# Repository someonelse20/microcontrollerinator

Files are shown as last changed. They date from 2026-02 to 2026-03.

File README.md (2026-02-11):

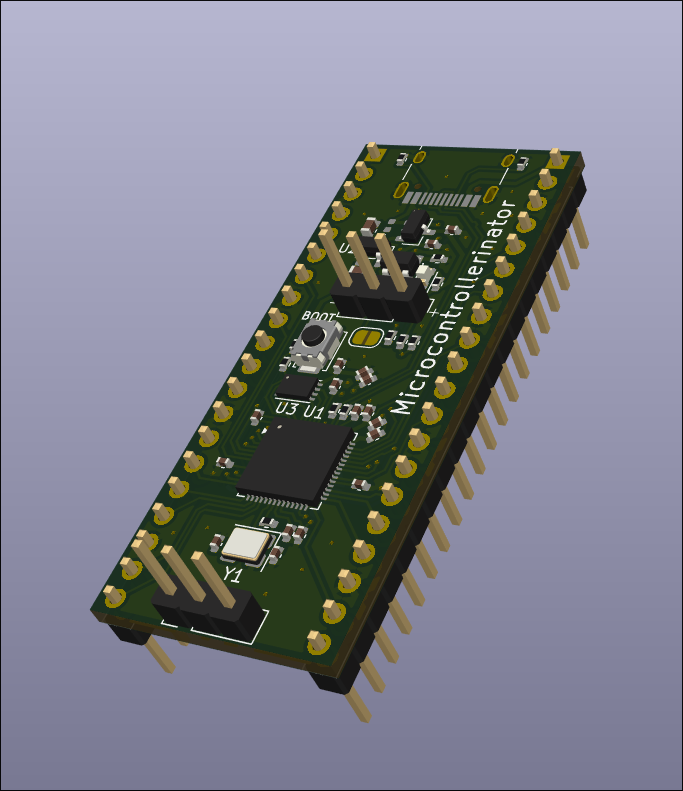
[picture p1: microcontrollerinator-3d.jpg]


# Microcontrollerinator
Simple custom devboard based on the RP2040 with an integraded 1 cell li-ion charger and Dr. Doofenshmirtz because why not.
This is my first complex pcb and to get my feet wet I mostly followed the example at https://blueprint.hackclub.com/starter-projects/devboard and added the BQ21040DBV battery charger. 

# How To Use
The board has the same pinout as the Raspberry Pi Pico exept ADC_VREF is GPIO23, 3V3_EN is GPIO24, and VSYS is GPIO25. GPIO29_ADC3 monitors the voltage of the battery multiplied by 1.3125 due to the resistor dividor. Pressing the switch will put the RP2040 into boot mode so it can be programed. The VBUS pin will output the current power supply voltage which will be 5v when plugged in but will be the direct battery voltage when unplugged. The battery pin headder has three pins, two for power and one for a thermistor to monitor temperature. The thermistor can be left hanging but there is a solder pad that enables a pull up resistor which is recomended in the charger datasheet.

# Schematic
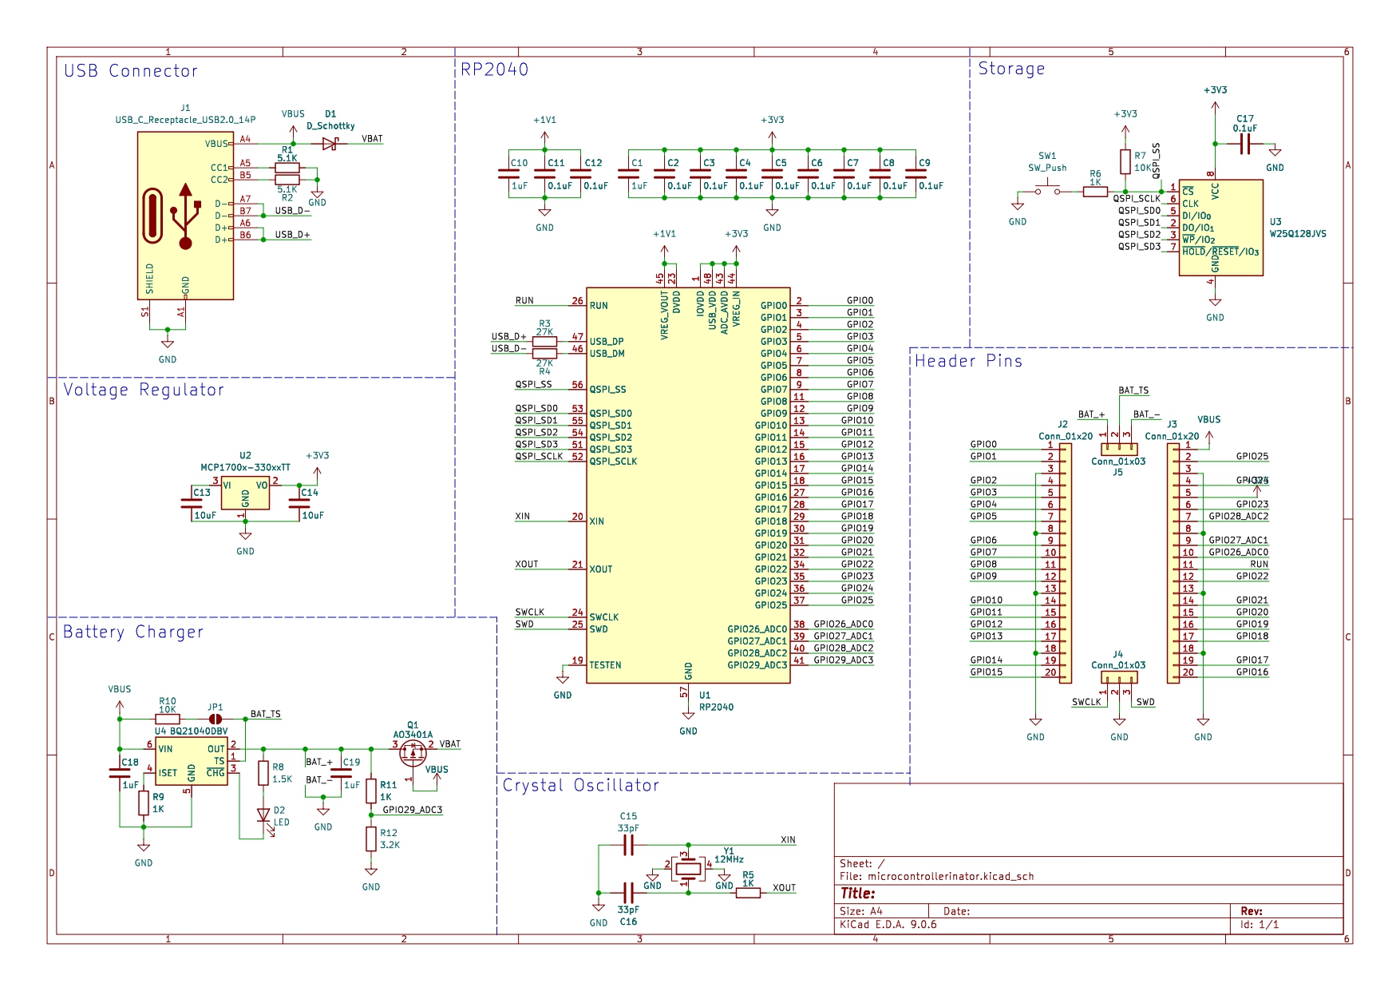
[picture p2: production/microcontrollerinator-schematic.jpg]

# PCB
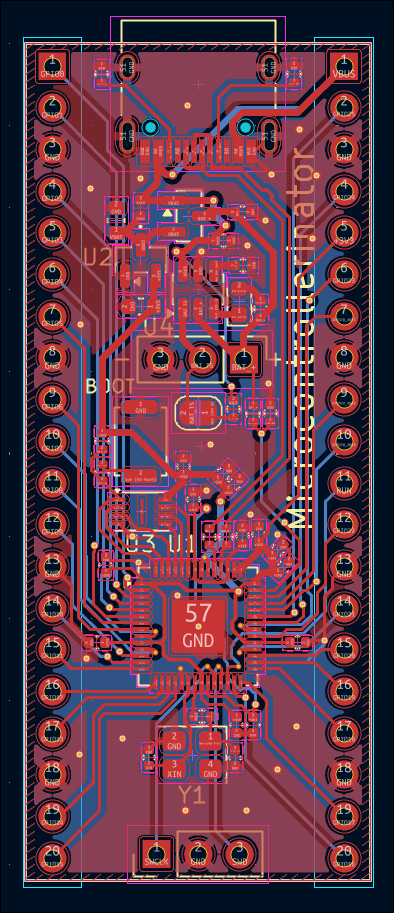
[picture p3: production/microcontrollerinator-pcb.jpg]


# Ordering
This bom file, the cpl position file, and the gerber zip files are in the production folder and formated to be orederd from https://jlcpcb.com/. The positions file needs to be edited a bit and there isn't an option to export the updated cpl file for JLCPCB so edit as show in the picture below. The USB header goes down a little, U2 pin 1 goes to the bottom left, U3 pin 1 goes to the top left, U4 pin 1 goes to the bottom left, and Q1 pin 1 goes to the top left.
| Id | Designator | Footprint | Quantity | Comment | Lcsc part |
| :---- | :--- | :--- | :--- | :--- | :--- |
| 1 | Y1 | Crystal_SMD_3225-4Pin_3.2x2.5mm | 1 | 12MHz | C9002 |
| 2 | SW1 | SW_Push_SPST_NO_Alps_SKRK | 1 | SW_Push | C720477 |
| 3 | C16,C15 | C_0402_1005Metric | 2 | 33pF | C1562 |
| 4 | C5,C3,C4,C8,C2,C11,C9,C12,C6,C7,C17 | C_0402_1005Metric | 11 | 0.1uF | C1525 |
| 5 | J4,J5 | PinHeader_1x03_P2.54mm_Vertical | 2 | Conn_01x03 | |
| 6 | R6,R11,R9,R5 | R_0402_1005Metric | 4 | 1K | C11702 |
| 7 | R2,R1 | R_0402_1005Metric | 2 | 5.1K | C25905 |
| 8 | U2 | SOT-23 | 1 | MCP1700x-330xxTT | C39051 |
| 9 | C14,C13 | C_0603_1608Metric | 2 | 10uF | C19702 |
| 10 | C10,C1,C19,C18 | C_0402_1005Metric | 4 | 1uF | C52923 |
| 11 | J1 | USB_C_Receptacle_HRO_TYPE-C-31-M-12 | 1 | USB_C_Receptacle_USB2.0_14P | C165948 |
| 12 | U3 | Winbond_USON-8-1EP_3x2mm_P0.5mm_EP0.2x1.6mm | 1 | W25Q128JVS | C2843335  |
| 13 | D2 | LED_0603_1608Metric | 1 | LED | C2290 |
| 14 | U4 | SOT-23-6 | 1 | BQ21040DBV | C202311 |
| 15 | R8 | R_0402_1005Metric | 1 | 1.5K | C25867 |
| 16 | R12 | R_0402_1005Metric | 1 | 3.2K | C705066 |
| 17 | U1 | QFN-56-1EP_7x7mm_P0.4mm_EP3.2x3.2mm | 1 | RP2040 | C2040 |
| 18 | D1 | D_0402_1005Metric | 1 | D_Schottky | C28646371 |
| 19 | Q1 | SOT-23 | 1 | AO3401A | C15127 |
| 20 | R4,R3 | R_0402_1005Metric | 2 | 27K | C11896 |
| 21 | R10,R7 | R_0402_1005Metric | 2 | 10K | C25744 |
| 22 | J3,J2 | PinHeader_1x20_P2.54mm_Vertical | 2 | Conn_01x20 | |

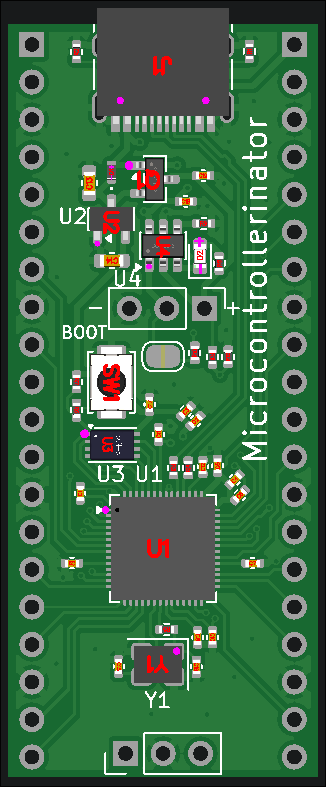
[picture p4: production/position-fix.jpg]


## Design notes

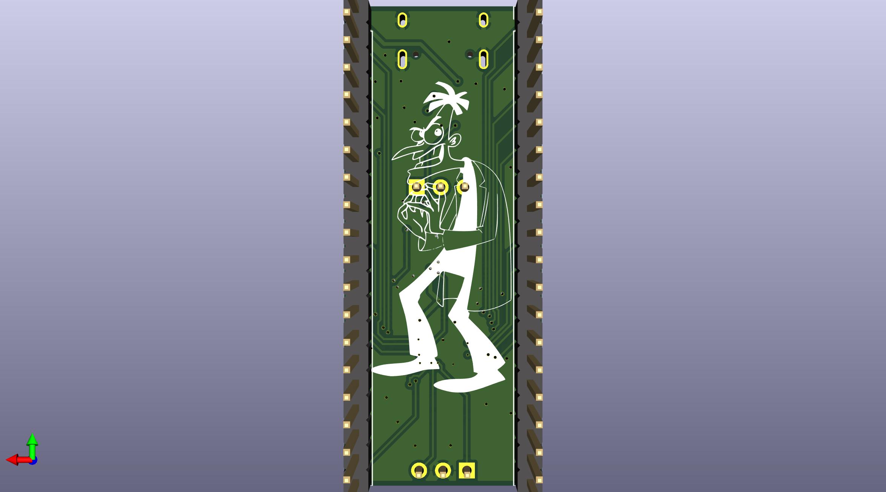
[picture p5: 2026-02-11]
microcontrollerinator-3d-back.jpg

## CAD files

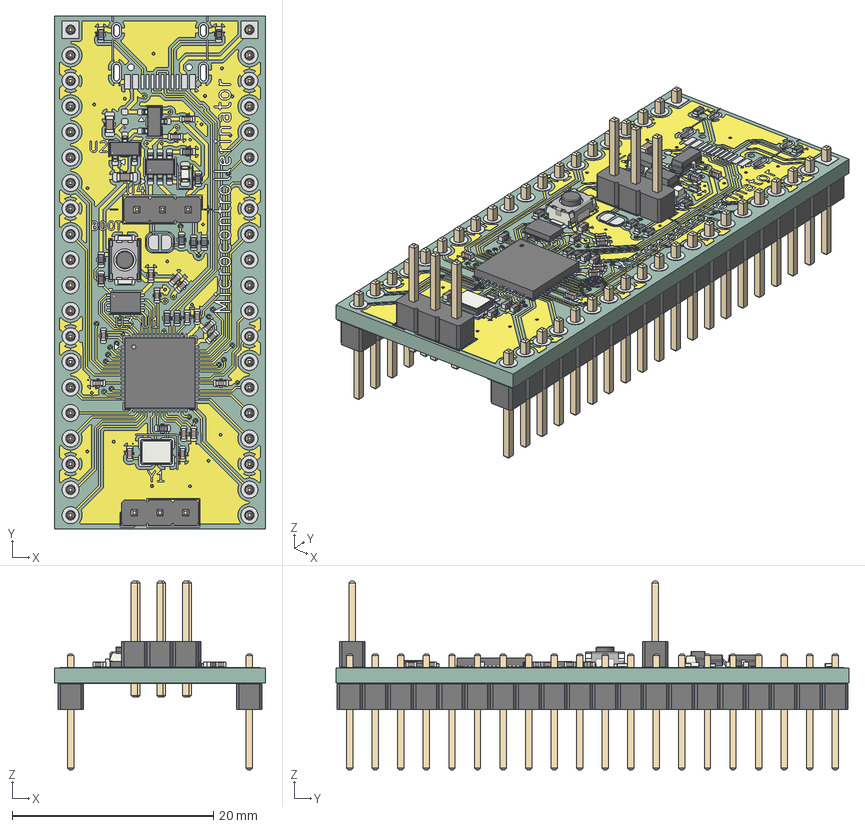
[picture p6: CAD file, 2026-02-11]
production/microcontrollerinator.step
21.0 x 51.0 x 18.8 mm
Crystal_SMD_3225-4Pin_3.2x2.5mm
SW_Push_SPST_NO_Alps_SKRK
C_0402_1005Metric x 17
PinHeader_1x03_P2.54mm_Vertical x 2
R_0402_1005Metric x 12
SOT-23 x 2
C_0603_1608Metric x 2
Winbond_USON-8-1EP_3x2mm_P0.5mm_EP0.2x1.6mm
LED_0603_1608Metric
SOT-23-6
QFN-56-1EP_7x7mm_P0.4mm_EP3.2x3.2mm
PinHeader_1x20_P2.54mm_Vertical x 2
microcontrollerinator_copper
microcontrollerinator_pad
microcontrollerinator_via
microcontrollerinator_silkscreen x 2
microcontrollerinator_PCB

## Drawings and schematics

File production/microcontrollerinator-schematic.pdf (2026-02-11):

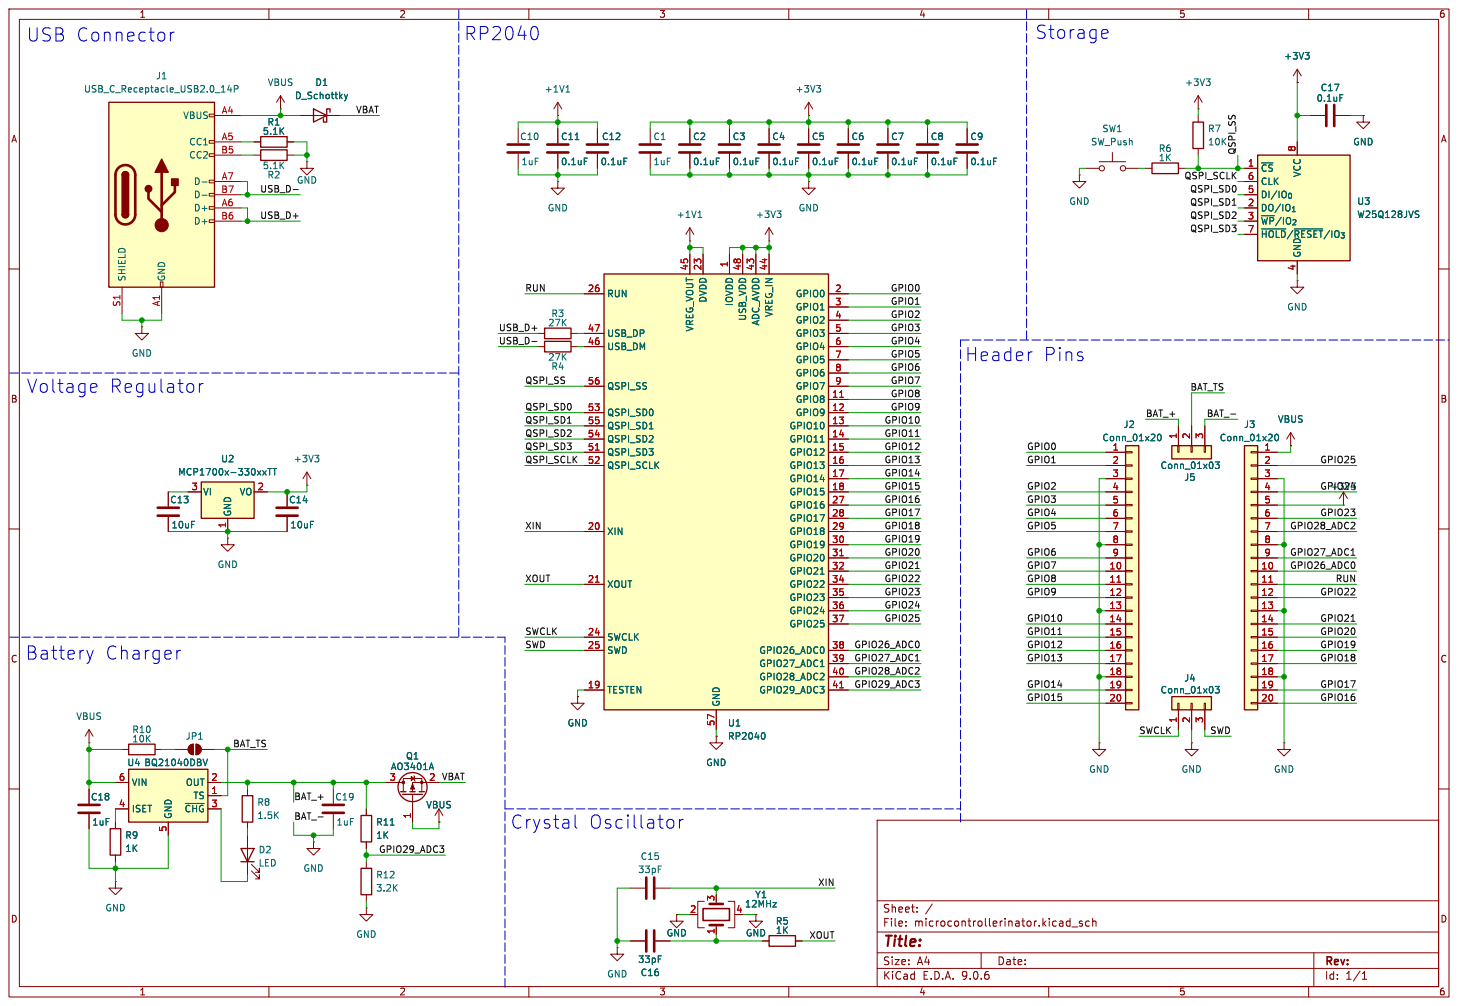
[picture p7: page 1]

Id: 1/1 Title: File: microcontrollerinator.kicad_sch Sheet: / GND GND

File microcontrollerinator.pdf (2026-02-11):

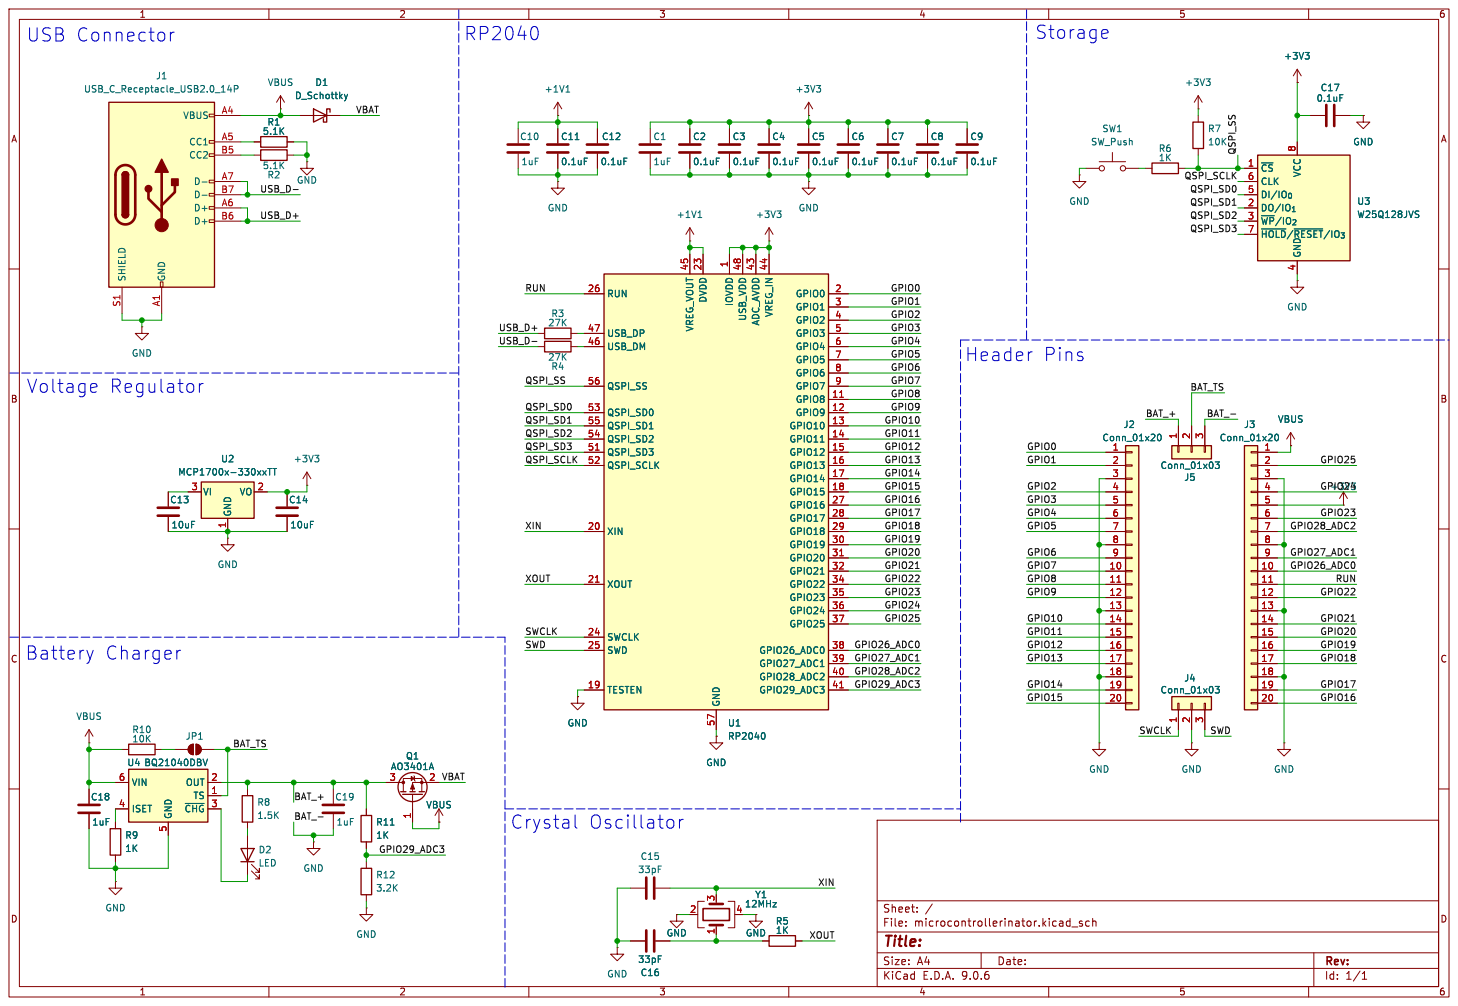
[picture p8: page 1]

1 VO 2 U2 MCP1700x-330xxTT RUN 26 USB_DP 47 USB_DM 46 QSPI_SS 56 QSPI_SD0 53 QSPI_SD1 55 QSPI_SD2 54 QSPI_SD3 51 QSPI_SCLK 52 XIN 20 XOUT 21 SWCLK 24 SWD 25 TESTEN 19 VREG_VOUT 45 DVDD 23 GND 57 IOVDD

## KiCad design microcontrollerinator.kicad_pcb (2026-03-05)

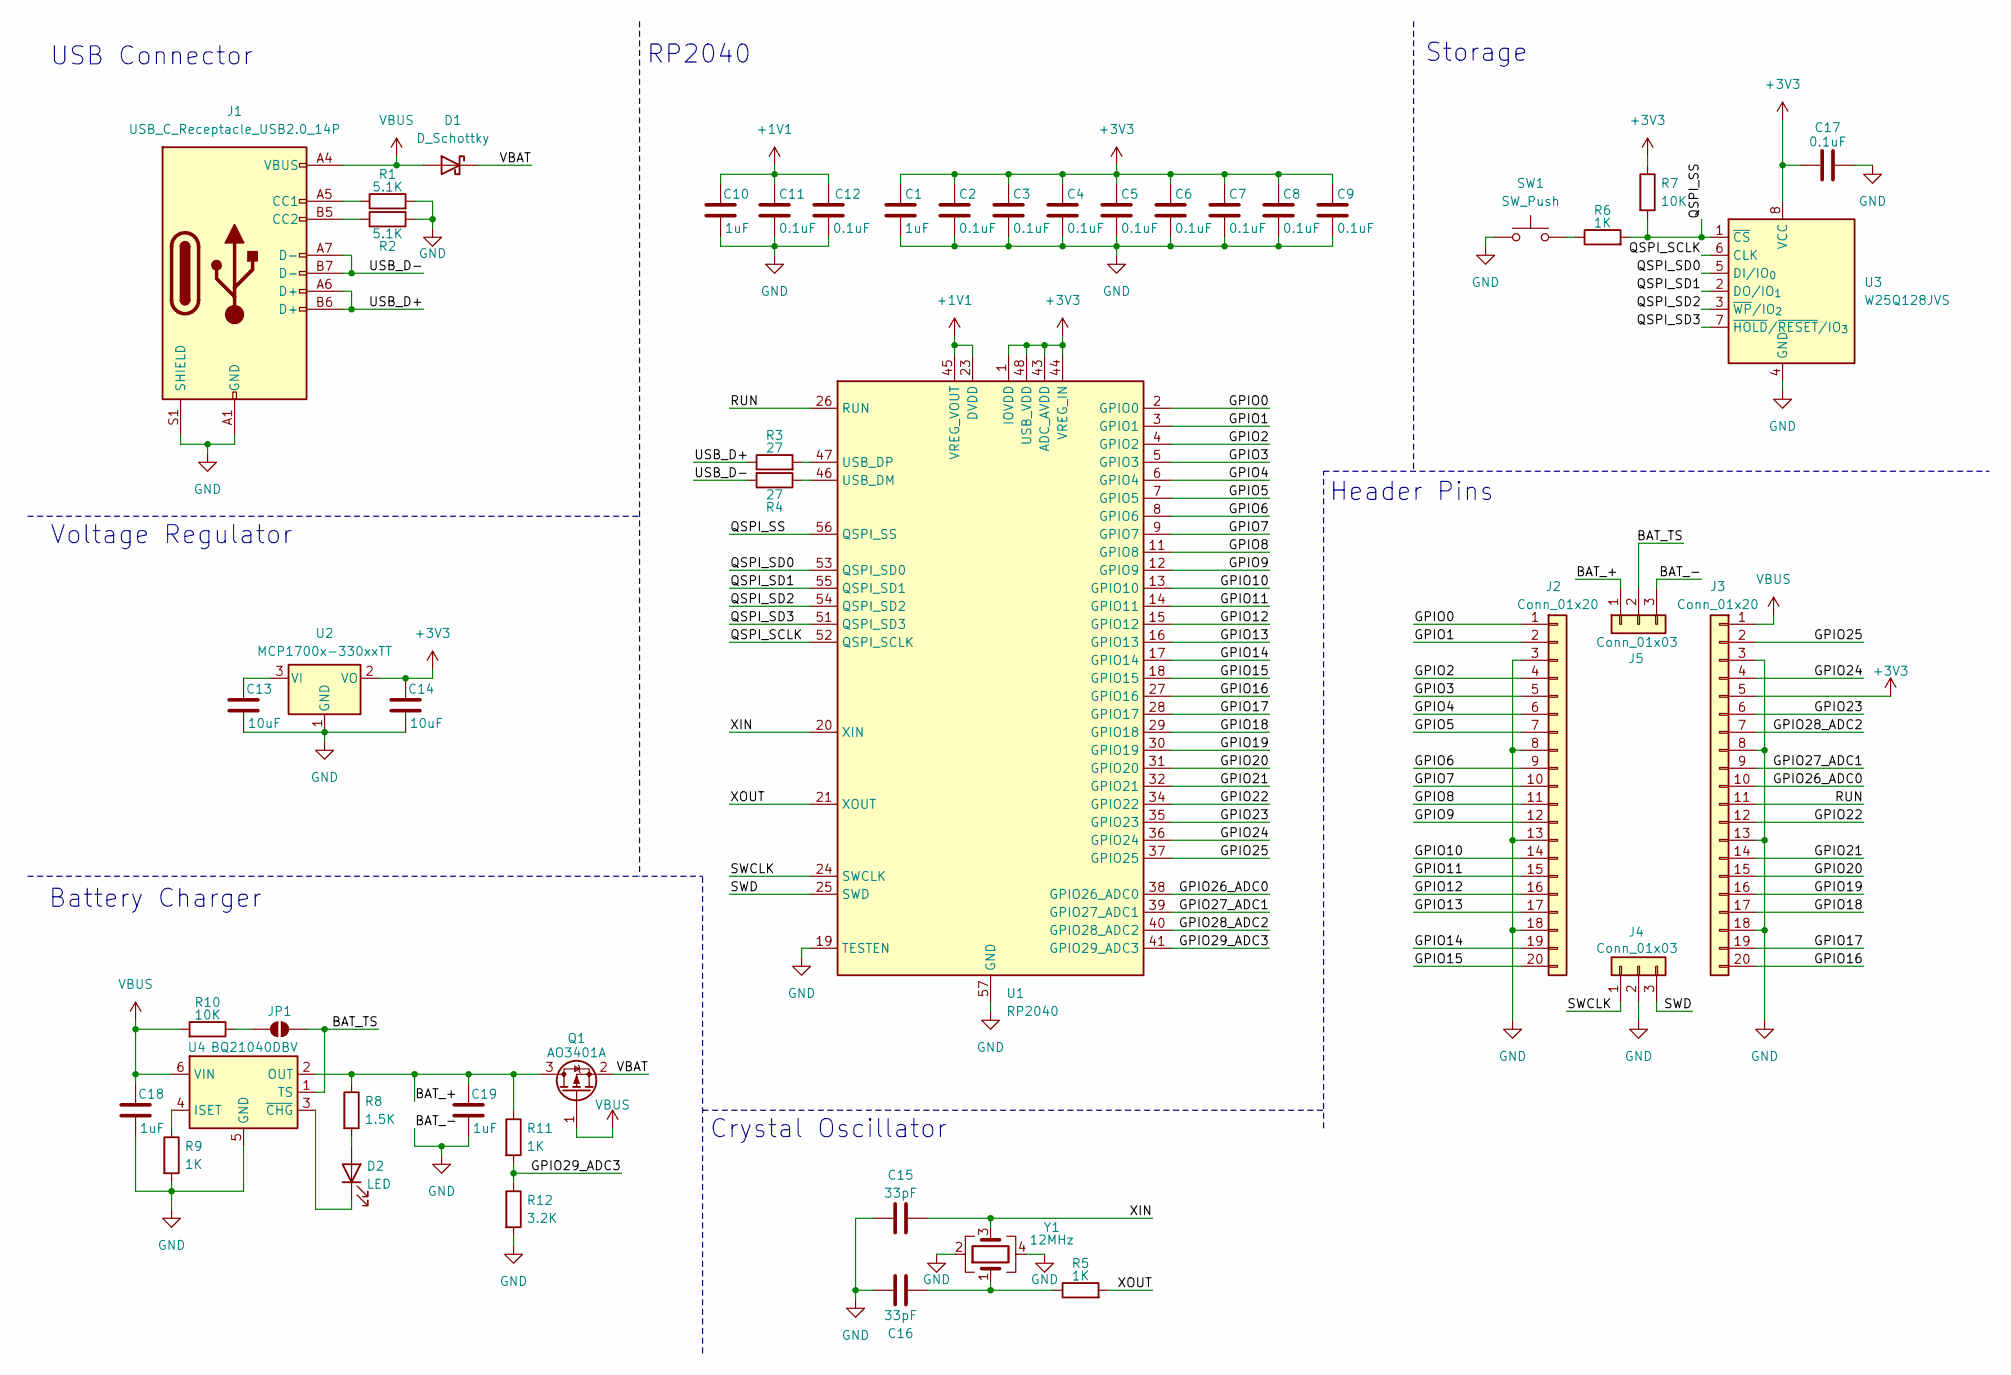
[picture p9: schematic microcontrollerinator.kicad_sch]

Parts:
C1, C10, C18, C19: 1uF; C_0402_1005Metric
C2, C3, C4, C5, C6, C7, C8, C9, C11, C12, C17: 0.1uF; C_0402_1005Metric
C13, C14: 10uF; C_0603_1608Metric
C15, C16: 33pF; C_0402_1005Metric
D1: D_Schottky; D_0402_1005Metric
D2: LED; LED_0603_1608Metric
J1: USB_C_Receptacle_USB2.0_14P; USB_C_Receptacle_HRO_TYPE-C-31-M-12
J2, J3: Conn_01x20; PinHeader_1x20_P2.54mm_Vertical
J4, J5: Conn_01x03; PinHeader_1x03_P2.54mm_Vertical
JP1: SolderJumper_2_Open; SolderJumper-2_P1.3mm_Open_RoundedPad1.0x1.5mm
Q1: AO3401A; SOT-23
R1, R2: 5.1K; R_0402_1005Metric
R3, R4: 27; R_0402_1005Metric
R5, R6, R9, R11: 1K; R_0402_1005Metric
R7, R10: 10K; R_0402_1005Metric
R8: 1.5K; R_0402_1005Metric
R12: 3.2K; R_0402_1005Metric
SW1: SW_Push; SW_Push_SPST_NO_Alps_SKRK
U1: RP2040; QFN-56-1EP_7x7mm_P0.4mm_EP3.2x3.2mm
U2: MCP1700x-330xxTT; SOT-23
U3: W25Q128JVS; Winbond_USON-8-1EP_3x2mm_P0.5mm_EP0.2x1.6mm
U4: BQ21040DBV; SOT-23-6
Y1: 12MHz; Crystal_SMD_3225-4Pin_3.2x2.5mm

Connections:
+1V1: C10.1, C11.1, C12.1, U1.23 (DVDD), U1.45 (VREG_VOUT), U1.50 (DVDD)
+3V3: C1.1, C2.1, C3.1, C4.1, C5.1, C6.1, C7.1, C8.1, C9.1, C14.1, C17.1, J3.5, R7.1, U1.1 (IOVDD), U1.10 (IOVDD), U1.22 (IOVDD), U1.33 (IOVDD), U1.42 (IOVDD), U1.43 (ADC_AVDD), U1.44 (VREG_IN), U1.48 (USB_VDD), U1.49 (IOVDD), U2.2 (VO), U3.8 (VCC)
/BAT_+: C19.1, J5.1, Q1.3 (D), R8.1, R11.1, U4.2 (OUT)
/BAT_TS: J5.2, JP1.2 (B), U4.1 (TS)
/GPIO0: J2.1, U1.2 (GPIO0)
/GPIO1: J2.2, U1.3 (GPIO1)
/GPIO2: J2.4, U1.4 (GPIO2)
/GPIO3: J2.5, U1.5 (GPIO3)
/GPIO4: J2.6, U1.6 (GPIO4)
/GPIO5: J2.7, U1.7 (GPIO5)
/GPIO6: J2.9, U1.8 (GPIO6)
/GPIO7: J2.10, U1.9 (GPIO7)
/GPIO8: J2.11, U1.11 (GPIO8)
/GPIO9: J2.12, U1.12 (GPIO9)
/GPIO10: J2.14, U1.13 (GPIO10)
/GPIO11: J2.15, U1.14 (GPIO11)
/GPIO12: J2.16, U1.15 (GPIO12)
/GPIO13: J2.17, U1.16 (GPIO13)
/GPIO14: J2.19, U1.17 (GPIO14)
/GPIO15: J2.20, U1.18 (GPIO15)
/GPIO16: J3.20, U1.27 (GPIO16)
/GPIO17: J3.19, U1.28 (GPIO17)
/GPIO18: J3.17, U1.29 (GPIO18)
/GPIO19: J3.16, U1.30 (GPIO19)
/GPIO20: J3.15, U1.31 (GPIO20)
/GPIO21: J3.14, U1.32 (GPIO21)
/GPIO22: J3.12, U1.34 (GPIO22)
/GPIO23: J3.6, U1.35 (GPIO23)
/GPIO24: J3.4, U1.36 (GPIO24)
/GPIO25: J3.2, U1.37 (GPIO25)
/GPIO26_ADC0: J3.10, U1.38 (GPIO26_ADC0)
/GPIO27_ADC1: J3.9, U1.39 (GPIO27_ADC1)
/GPIO28_ADC2: J3.7, U1.40 (GPIO28_ADC2)
/GPIO29_ADC3: R11.2, R12.1, U1.41 (GPIO29_ADC3)
/QSPI_SCLK: U1.52 (QSPI_SCLK), U3.6 (CLK)
/QSPI_SD0: U1.53 (QSPI_SD0), U3.5 (DI/IO_{0})
/QSPI_SD1: U1.55 (QSPI_SD1), U3.2 (DO/IO_{1})
/QSPI_SD2: U1.54 (QSPI_SD2), U3.3 (~WP/IO_{2})
/QSPI_SD3: U1.51 (QSPI_SD3), U3.7 (~HOLD/~RESET/IO_{3})
/QSPI_SS: R6.2, R7.2, U1.56 (QSPI_SS), U3.1 (~CS)
/RUN: J3.11, U1.26 (RUN)
/SWCLK: J4.1, U1.24 (SWCLK)
/SWD: J4.3, U1.25 (SWD)
/USB_D+: J1.A6 (D+), J1.B6 (D+), R3.1
/USB_D-: J1.A7 (D-), J1.B7 (D-), R4.2
/VBAT: D1.1 (K), Q1.2 (S)
/XIN: C15.2, U1.20 (XIN), Y1.3
/XOUT: R5.2, U1.21 (XOUT)
GND: C1.2, C2.2, C3.2, C4.2, C5.2, C6.2, C7.2, C8.2, C9.2, C10.2, C11.2, C12.2, C13.2, C14.2, C15.1, C16.2, C17.2, C18.2, C19.2, J1.A1 (GND), J1.A12 (GND), J1.B1 (GND), J1.B12 (GND), J1.S1 (SHIELD), J2.3, J2.8, J2.13, J2.18, J3.3, J3.8, J3.13, J3.18, J4.2, J5.3, R1.2, R2.2, R9.2, R12.2, SW1.1, U1.19 (TESTEN), U1.57 (GND), U2.1 (GND), U3.4 (GND), U4.5 (GND), Y1.2, Y1.4
unnamed: C16.1, R5.1, Y1.1
unnamed: D2.2 (A), R8.2
unnamed: D2.1 (K), U4.3 (~CHG)
unnamed: J1.A5 (CC1), R1.1
unnamed: J1.B5 (CC2), R2.1
unnamed: JP1.1 (A), R10.1
unnamed: R6.1, SW1.2
unnamed: R4.1, U1.46 (USB_DM)
unnamed: R3.2, U1.47 (USB_DP)
unnamed: C13.1, U2.3 (VI)
unnamed: R9.1, U4.4 (ISET)
VBUS: C18.1, D1.2 (A), J1.A4 (VBUS), J1.A9 (VBUS), J1.B4 (VBUS), J1.B9 (VBUS), J3.1, Q1.1 (G), R10.2, U4.6 (VIN)

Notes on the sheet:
Voltage Regulator
Header Pins
Crystal Oscillator
Battery Charger
Storage
RP2040
USB Connector

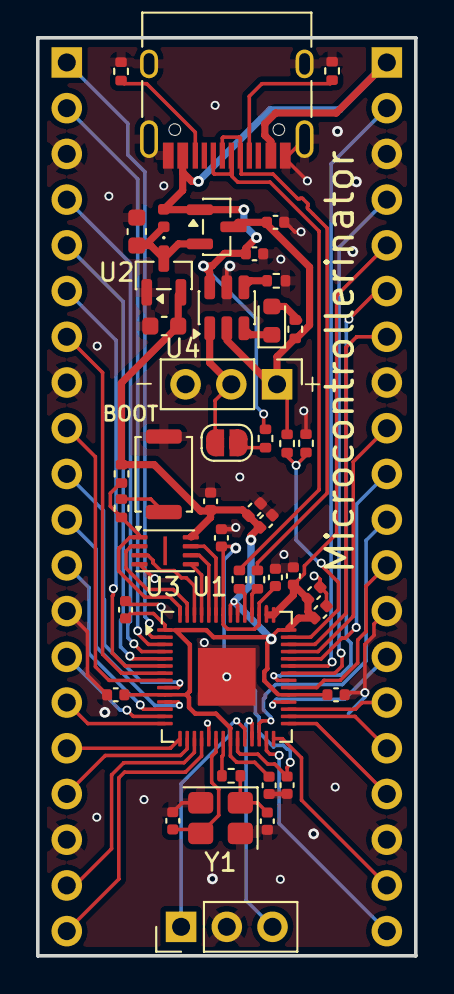
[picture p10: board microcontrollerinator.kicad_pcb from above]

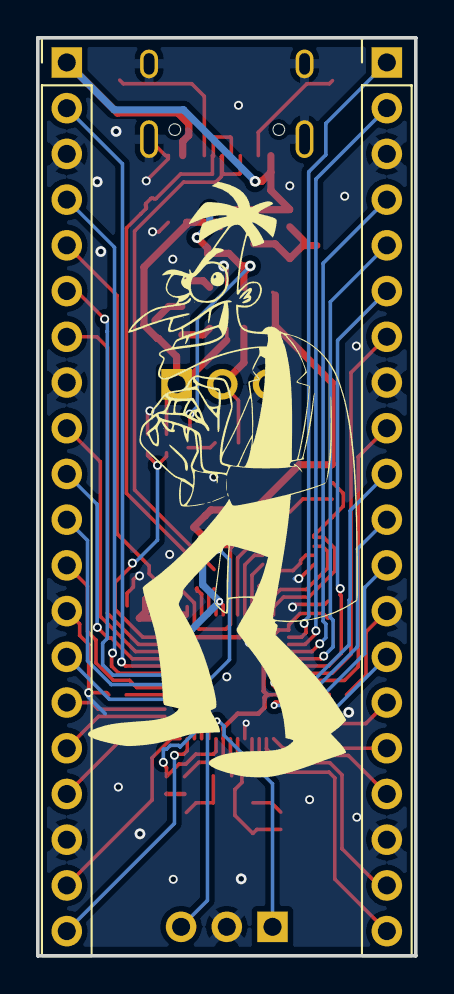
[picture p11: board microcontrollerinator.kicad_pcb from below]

Board: 2 copper layers, 21.0 x 51.0 mm, 46 parts (2 on the bottom side), 61 nets.

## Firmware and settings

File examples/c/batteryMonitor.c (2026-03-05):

/*
 * THIS PROGRAM IS UNTESTED AND MAY NOT WORK.
 * Modified ADC example from pico sdk.
 * Monitors voltage of connected battery.
 */
#include "hardware/adc.h"
#include "pico/stdlib.h"
#include <stdio.h>

int main() {
  setup_default_uart();
  stdio_init_all();
  printf("ADC Example, measuring battery voltage\n");

  adc_init();

  // Make sure GPIO is high-impedance, no pullups etc
  adc_gpio_init(29);
  // Select ADC input 3 (GPIO29)
  adc_select_input(3);

  while (1) {
    // 12-bit conversion, assume max value == ADC_VREF == 3.3 V, multiply
    // by 1.3125 to get actual voltage of battery.
    const float conversion_factor = (3.3f / (1 << 12)) * 1.3125;
    uint16_t result = adc_read();
    printf("Raw value: 0x%03x, Battery voltage: %f V\n", result,
           result * conversion_factor);
    sleep_ms(500);
  }
}

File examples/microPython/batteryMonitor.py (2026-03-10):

# Simple program to monitor the voltage of the connected battery.
import machine
import utime

batt_monitor = machine.ADC(29) # GPIO 29

while True:
    batt_voltage = batt_monitor.read_u16() * (4.2 / 65535) # Multiply to get actual battery voltage after voltage dividor.
    print("Battery voltage: ", batt_voltage)
    utime.sleep(0.2)

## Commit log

2026-02-06 first draft of schematic
    [microcontrollerinator.kicad_pcb, microcontrollerinator.kicad_sch]
2026-02-06 routing pcb
    [microcontrollerinator.kicad_pcb, microcontrollerinator.kicad_sch]
2026-02-07 finished routing pcb
    [microcontrollerinator.kicad_pcb, microcontrollerinator.kicad_sch]
2026-02-07 added production files
    [microcontrollerinator-B_Cu.gbr, microcontrollerinator-B_Mask.gbr, microcontrollerinator-B_Paste.gbr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]
2026-02-09 fixed 3d model
    [microcontrollerinator.kicad_pcb]
2026-02-09 checked pcb
    [microcontrollerinator.kicad_pcb, microcontrollerinator.kicad_sch]
2026-02-11 finished board
    [bom.csv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]
2026-02-11 added .step file
    [microcontrollerinator.step]
2026-02-11 cleaned up schematic
    [microcontrollerinator.kicad_sch]
2026-03-05 fixed pcb
    [microcontrollerinator.kicad_pcb, microcontrollerinator.kicad_sch]
2026-03-05 added battery drain script
2026-03-05 added batteryDrain.c
